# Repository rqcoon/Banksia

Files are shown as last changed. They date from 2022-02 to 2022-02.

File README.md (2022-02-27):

# Banksia

a 4x10 ortholinear bluetooth keyboard

bottom row is fixed 2x2 stabless (plate mount stabs possible)

[KLE link](http://www.keyboard-layout-editor.com/#/gists/ac4e33216322b06a96d62318165e8864)

Front

Back

this repo is just kicad files lol do whatever

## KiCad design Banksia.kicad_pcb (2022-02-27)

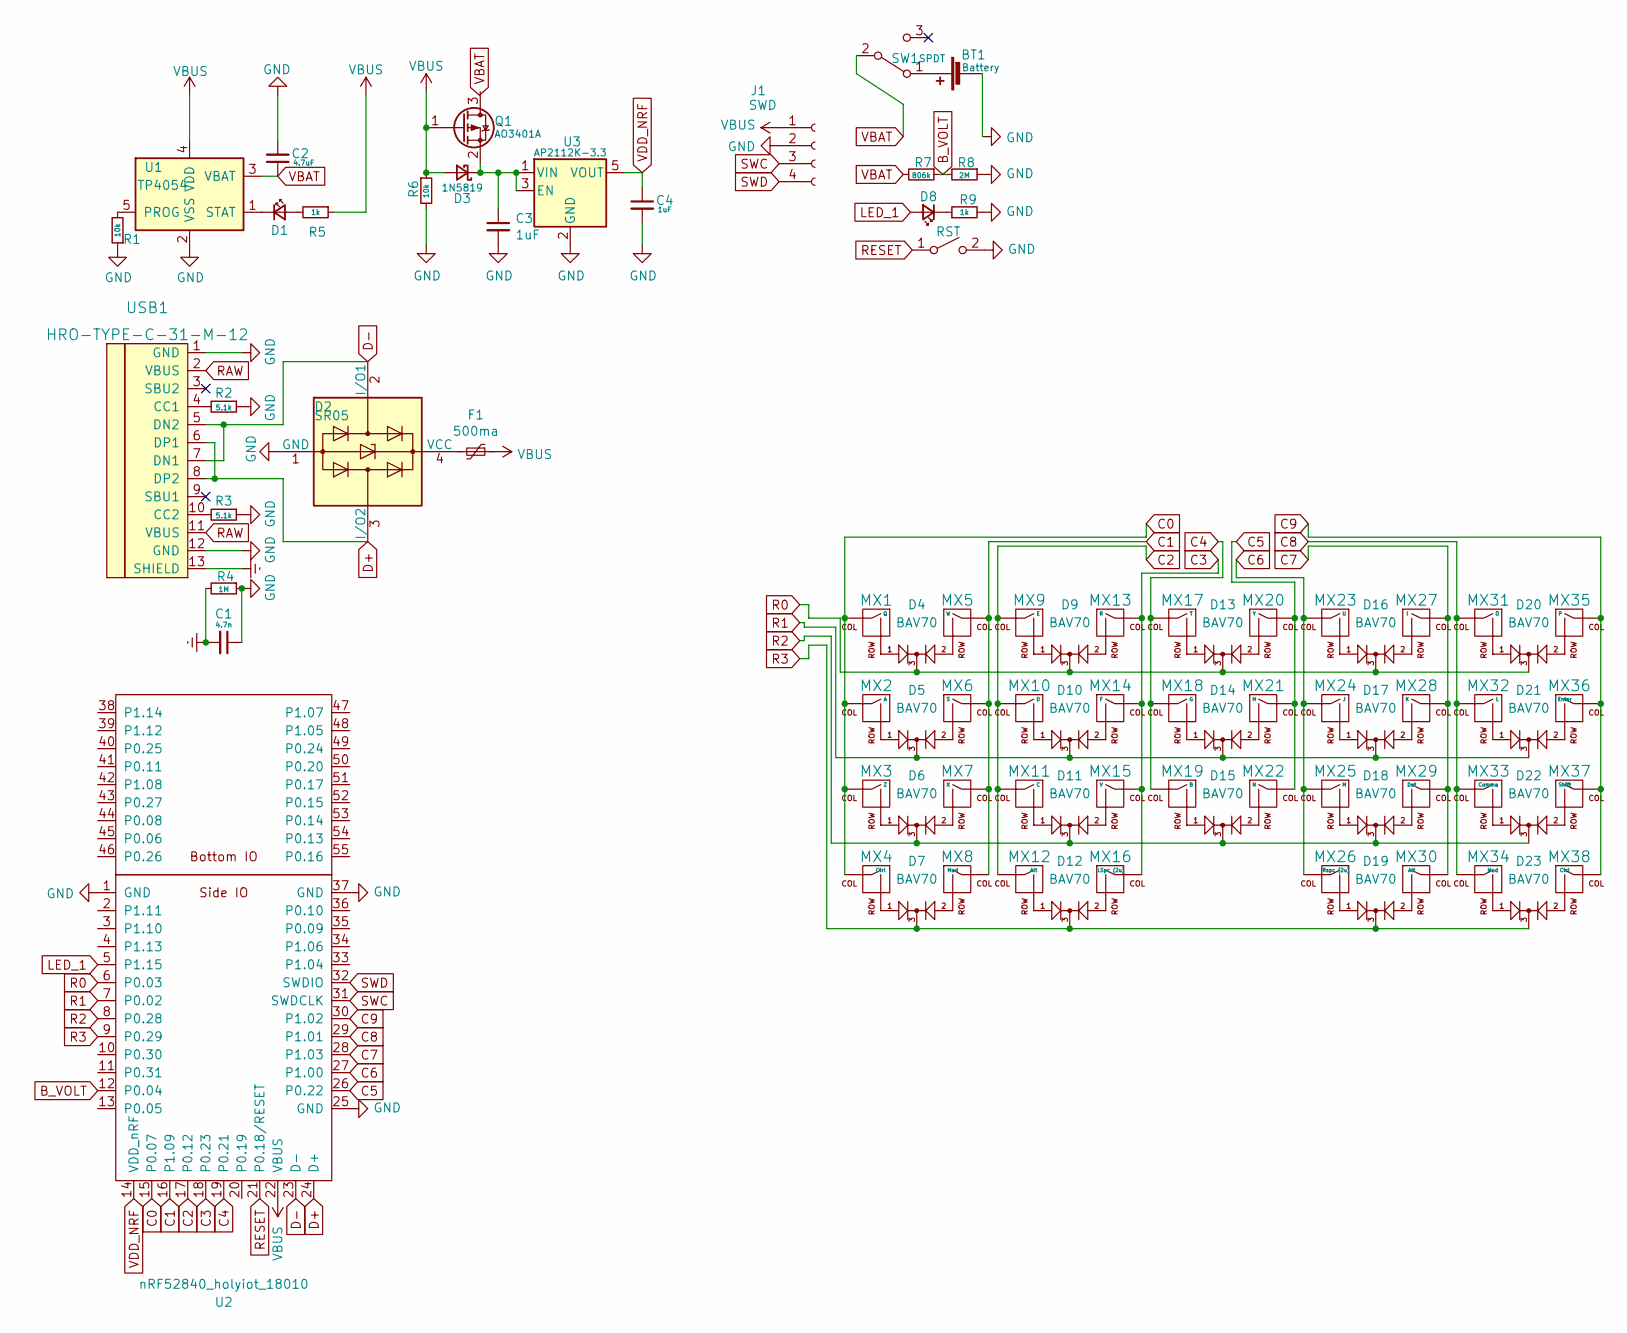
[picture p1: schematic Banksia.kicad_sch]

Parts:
BT1: Battery; JST_SH_BM02B-SRSS-TB_1x02-1MP_P1.00mm_Vertical
C1: 4.7n; C_1206_3216Metric
C2: 4.7uF; C_0805_2012Metric
C3, C4: 1uF; C_0805_2012Metric
D1: POWERLED; D_0805_2012Metric
D2: SR05; SOT-143
D3: 1N5819; D_SOD-123
D4, D5, D6, D7, D9, D10, D11, D12, D13, D14, D15, D16, D17, D18, D19, D20, D21, D22, D23: BAV70; SOT-23
D8: LED; D_0805_2012Metric
F1: 500ma; Fuse_1206_3216Metric
J1: SWD; PinHeader_1x04_P2.54mm_Vertical
MX1: Q; MXOnly-1U-NoLED
MX2: A; MXOnly-1U-NoLED
MX3: Z; MXOnly-1U-NoLED
MX4, MX38: Ctrl; MXOnly-1U-NoLED
MX5: W; MXOnly-1U-NoLED
MX6: S; MXOnly-1U-NoLED
MX7: X; MXOnly-1U-NoLED
MX8, MX34: Mod; MXOnly-1U-NoLED
MX9: E; MXOnly-1U-NoLED
MX10: D; MXOnly-1U-NoLED
MX11: C; MXOnly-1U-NoLED
MX12, MX30: Alt; MXOnly-1U-NoLED
MX13: R; MXOnly-1U-NoLED
MX14: F; MXOnly-1U-NoLED
MX15: V; MXOnly-1U-NoLED
MX16: LSpc (2u); MXOnly-1U-NoLED
MX17: T; MXOnly-1U-NoLED
MX18: G; MXOnly-1U-NoLED
MX19: B; MXOnly-1U-NoLED
MX20: Y; MXOnly-1U-NoLED
MX21: H; MXOnly-1U-NoLED
MX22: N; MXOnly-1U-NoLED
MX23: U; MXOnly-1U-NoLED
MX24: J; MXOnly-1U-NoLED
MX25: M; MXOnly-1U-NoLED
MX26: Rspc (2u); MXOnly-1U-NoLED
MX27: I; MXOnly-1U-NoLED
MX28: K; MXOnly-1U-NoLED
MX29: Dot; MXOnly-1U-NoLED
MX31: O; MXOnly-1U-NoLED
MX32: L; MXOnly-1U-NoLED
MX33: Comma; MXOnly-1U-NoLED
MX35: P; MXOnly-1U-NoLED
MX36: Enter; MXOnly-1U-NoLED
MX37: Shift; MXOnly-1U-NoLED
Q1: AO3401A; SOT-23
R1, R6: 10k; R_0805_2012Metric
R2, R3: 5.1k; R_0805_2012Metric
R4: 1M; R_0805_2012Metric
R5, R9: 1k; R_0805_2012Metric
R7: 806k; R_0805_2012Metric
R8: 2M; R_0805_2012Metric
SW1: SPDT; SW_CuK_OS102011MA1QN1_SPDT_Angled
SW2: RST; SW_SPST_SKQG_WithStem
U1: TP4054; SOT-23-5
U2: nRF52840_holyiot_18010
U3: AP2112K-3.3; SOT-23-5
USB1: HRO-TYPE-C-31-M-12; HRO-TYPE-C-31-M-12-Assembly

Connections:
B_VOLT: R7.1, R8.2, U2.12 (P0.04)
C0: MX1.1 (COL), MX2.1 (COL), MX3.1 (COL), MX4.1 (COL), U2.15 (P0.07)
C1: MX5.1 (COL), MX6.1 (COL), MX7.1 (COL), MX8.1 (COL), U2.16 (P1.09)
C2: MX9.1 (COL), MX10.1 (COL), MX11.1 (COL), MX12.1 (COL), U2.17 (P0.12)
C3: MX13.1 (COL), MX14.1 (COL), MX15.1 (COL), MX16.1 (COL), U2.18 (P0.23)
C4: MX17.1 (COL), MX18.1 (COL), MX19.1 (COL), U2.19 (P0.21)
C5: MX20.1 (COL), MX21.1 (COL), MX22.1 (COL), U2.26 (P0.22)
C6: MX23.1 (COL), MX24.1 (COL), MX25.1 (COL), MX26.1 (COL), U2.27 (P1.00)
C7: MX27.1 (COL), MX28.1 (COL), MX29.1 (COL), MX30.1 (COL), U2.28 (P1.03)
C8: MX31.1 (COL), MX32.1 (COL), MX33.1 (COL), MX34.1 (COL), U2.29 (P1.01)
C9: MX35.1 (COL), MX36.1 (COL), MX37.1 (COL), MX38.1 (COL), U2.30 (P1.02)
D+: D2.3 (I/O2), U2.24 (D+), USB1.6 (DP1), USB1.8 (DP2)
D-: D2.2 (I/O1), U2.23 (D-), USB1.5 (DN2), USB1.7 (DN1)
Earth: C1.2, R4.2, USB1.13 (SHIELD)
GND: BT1.2 (-), C1.1, C2.2, C3.2, C4.2, D2.1 (GND), J1.2, R1.1, R2.1, R3.1, R4.1, R6.2, R8.1, R9.2, SW2.2 (B), U1.2 (VSS), U2.1 (GND), U2.25 (GND), U2.37 (GND), U3.2 (GND), USB1.1 (GND), USB1.12 (GND)
LED_1: D8.2 (A), U2.5 (P1.15)
unnamed: BT1.1 (+), SW1.1 (A)
unnamed: C3.1, D3.1 (K), Q1.2 (S), U3.1 (VIN), U3.3 (EN)
unnamed: D1.1 (K), U1.1 (STAT)
unnamed: D1.2 (A), R5.2
unnamed: D2.4 (VCC), F1.2
unnamed: D4.1 (A1), MX1.2 (ROW)
unnamed: D4.2 (A2), MX5.2 (ROW)
unnamed: D5.1 (A1), MX2.2 (ROW)
unnamed: D5.2 (A2), MX6.2 (ROW)
unnamed: D6.1 (A1), MX3.2 (ROW)
unnamed: D6.2 (A2), MX7.2 (ROW)
unnamed: D7.1 (A1), MX4.2 (ROW)
unnamed: D7.2 (A2), MX8.2 (ROW)
unnamed: D8.1 (K), R9.1
unnamed: D9.1 (A1), MX9.2 (ROW)
unnamed: D9.2 (A2), MX13.2 (ROW)
unnamed: D10.1 (A1), MX10.2 (ROW)
unnamed: D10.2 (A2), MX14.2 (ROW)
unnamed: D11.1 (A1), MX11.2 (ROW)
unnamed: D11.2 (A2), MX15.2 (ROW)
unnamed: D12.1 (A1), MX12.2 (ROW)
unnamed: D12.2 (A2), MX16.2 (ROW)
unnamed: D13.1 (A1), MX17.2 (ROW)
unnamed: D13.2 (A2), MX20.2 (ROW)
unnamed: D14.1 (A1), MX18.2 (ROW)
unnamed: D14.2 (A2), MX21.2 (ROW)
unnamed: D15.1 (A1), MX19.2 (ROW)
unnamed: D15.2 (A2), MX22.2 (ROW)
unnamed: D16.1 (A1), MX23.2 (ROW)
unnamed: D16.2 (A2), MX27.2 (ROW)
unnamed: D17.1 (A1), MX24.2 (ROW)
unnamed: D17.2 (A2), MX28.2 (ROW)
unnamed: D18.1 (A1), MX25.2 (ROW)
unnamed: D18.2 (A2), MX29.2 (ROW)
unnamed: D19.1 (A1), MX26.2 (ROW)
unnamed: D19.2 (A2), MX30.2 (ROW)
unnamed: D20.1 (A1), MX31.2 (ROW)
unnamed: D20.2 (A2), MX35.2 (ROW)
unnamed: D21.1 (A1), MX32.2 (ROW)
unnamed: D21.2 (A2), MX36.2 (ROW)
unnamed: D22.1 (A1), MX33.2 (ROW)
unnamed: D22.2 (A2), MX37.2 (ROW)
unnamed: D23.1 (A1), MX34.2 (ROW)
unnamed: D23.2 (A2), MX38.2 (ROW)
unnamed: R1.2, U1.5 (PROG)
unnamed: R2.2, USB1.4 (CC1)
unnamed: R3.2, USB1.10 (CC2)
R0: D4.3 (K), D9.3 (K), D13.3 (K), D16.3 (K), D20.3 (K), U2.6 (P0.03)
R1: D5.3 (K), D10.3 (K), D14.3 (K), D17.3 (K), D21.3 (K), U2.7 (P0.02)
R2: D6.3 (K), D11.3 (K), D15.3 (K), D18.3 (K), D22.3 (K), U2.8 (P0.28)
R3: D7.3 (K), D12.3 (K), D19.3 (K), D23.3 (K), U2.9 (P0.29)
RAW: USB1.2 (VBUS), USB1.11 (VBUS)
RESET: SW2.1 (A), U2.21 (P0.18/RESET)
SWC: J1.3, U2.31 (SWDCLK)
SWD: J1.4, U2.32 (SWDIO)
VBAT: C2.1, R7.2, SW1.2 (B), U1.3 (VBAT)
VBUS: D3.2 (A), F1.1, J1.1, Q1.1 (G), R5.1, R6.1, U1.4 (VDD), U2.22 (VBUS)
VDD_NRF: C4.1, U2.14 (VDD_nRF), U3.5 (VOUT)

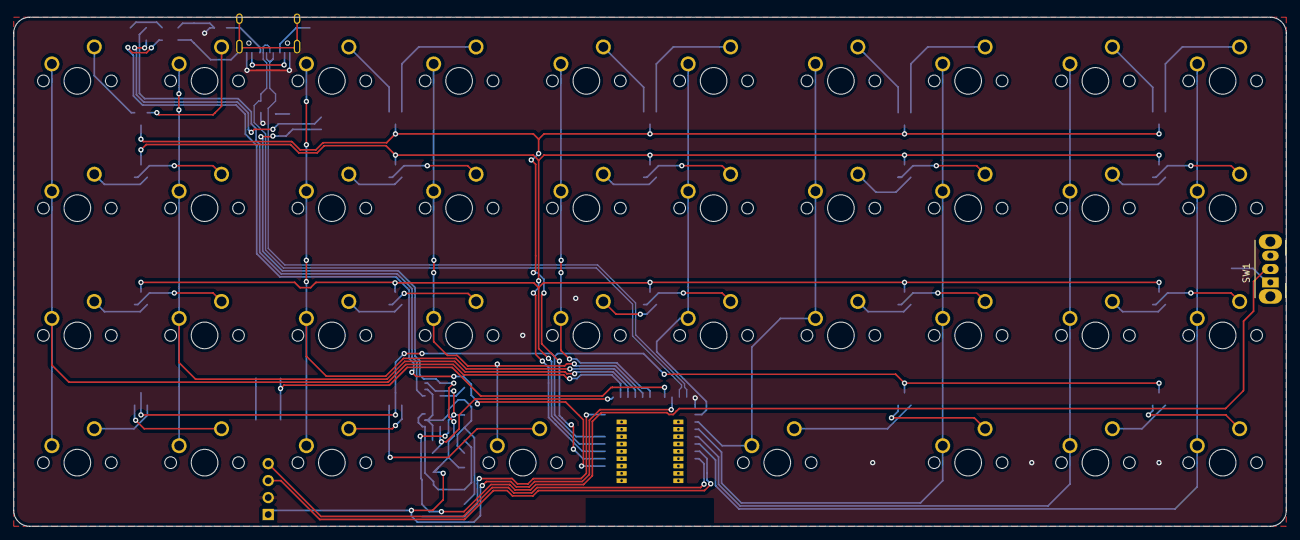
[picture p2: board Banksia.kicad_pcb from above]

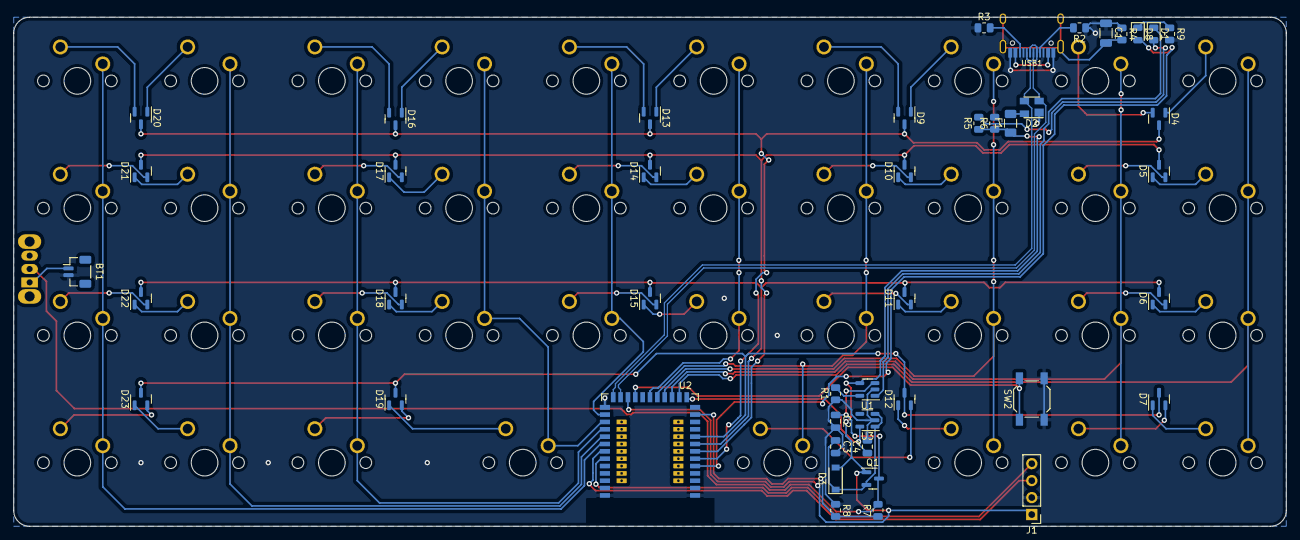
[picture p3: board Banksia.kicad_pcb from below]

Board: 2 copper layers, 190.5 x 76.2 mm, 84 parts (45 on the bottom side), 74 nets.
